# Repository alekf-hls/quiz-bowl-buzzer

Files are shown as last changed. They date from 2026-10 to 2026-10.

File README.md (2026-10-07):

# Quiz Bowl Buzzer

A wireless quiz bowl buzzer set: one ESP32 team station per team (up to 4 teams, 8 wired player buttons each) talking to an ESP32-S3 base that runs its own Wi-Fi network and serves a host page and a scoreboard.

Start with the [design doc](design/buzzer-design-v0.md).

- `design/` design doc, starter kit plan, wiring diagram, page previews
- `enclosures/` 3D-printable boxes (OpenSCAD sources and STLs), see [enclosures/README.md](enclosures/README.md)
- `firmware/base/data/` host page (`host.html`) and scoreboard (`board.html`) served by the base

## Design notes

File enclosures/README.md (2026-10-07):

# Quiz Bowl Buzzer enclosures

Parametric OpenSCAD (tested with OpenSCAD 2021.01) plus ready-to-print STLs for:

| Part | File | Outer size (W x D x H) |
|---|---|---|
| Team station box | `stl/team_station_box.stl` | 151 x 101 x 47 mm |
| Team station lid | `stl/team_station_lid.stl` | 151 x 101 x 3 mm (+4 mm lip) |
| Base station box | `stl/base_station_box.stl` | 180 x 125 x 47 mm |
| Base station lid | `stl/base_station_lid.stl` | 180 x 125 x 3 mm (+4 mm lip) |

Fits a 180 x 180 mm bed or larger. Previews are in `preview/`.

## What's where

**Team station** (one per team)
- Front: 8 holes for 3.5 mm TRRS panel jacks, a player light (5 mm RGB LED) above each one, seat numbers 1-8 below.
- Back: ESP32 USB opening (programming), the UPS board's USB-C opening (charging and wall power) and a 3 mm window for its charge LED.
- Right side: slide power switch.
- Lid: a 30 mm team button labelled TEAM (for playing as a team without the player buttons), big team number and "TEAM n" label. Print the lid in the team's colour. `team_button = false` removes the button hole. (`lid_led = true` adds an extra LED hole on the lid.)
- Inside: 4 tall (23 mm) standoffs for a 70 x 90 mm protoboard carrying the ESP32 DevKitC and ULN2803, with the 18650 holder in rails underneath it; a raised pocket for the USB-C UPS board. The area under the team button is kept clear.

**Base station**
- Lid, front to back: Arm / Correct / Wrong / Reset buttons with labels; a row of 4 team lights (5 mm RGB LEDs) numbered 1-4 (`teams` sets the count); the 1.3" OLED window (chamfered, with 4 M2 standoffs underneath for the module), Armed and Locked LEDs to its left and the buzzer grille with a glue-in ring to its right.
- Back: ESP32-S3 USB opening (wide enough for both USB-C ports).
- Right side: UPS board USB-C with a charge LED window, and the slide power switch.
- Inside: protoboard standoffs, 18650 rails along the back wall, UPS board pocket.

## Changing it

Open `team_station.scad` or `base_station.scad`; everything is a named variable at the top. Common ones:

- `team_label`, `team_num`: lid text per team (e.g. `openscad -D 'team_num="3"' -D 'team_label="TEAM 3"' -D 'part="lid"' -o lid3.stl team_station.scad`).
- `jacks`: number of player jacks (the box doesn't shrink automatically; reduce `X` too if you want a smaller box).
- `batt = false`: USB-only, drops the battery rails, UPS board pocket, switch and its USB-C opening.
- `btn_hole`: host button hole size (24.2 for 24 mm arcade, 16.2 or 12.2 for panel-mount momentaries).
- `screw_mode` in `common.scad`: `"selftap"` (M3 straight into plastic) or `"insert"` (M3 heat-set inserts).

Export: `openscad -D 'part="box"' -o box.stl team_station.scad` and the same with `part="lid"`. `part="assembly"` shows both.

## Assumed part dimensions (measure yours before printing)

| Part | Assumed | Where it matters |
|---|---|---|
| ESP32 DevKitC 38-pin | ~55 x 28 mm, micro-USB on a short end | USB opening centred 22 mm from the left inner wall |
| ESP32-S3 DevKitC-1 | ~63 x 26 mm, two USB-C on a short end | 24 x 8 mm opening at the same height |
| Board stack | standoff (23 mm station, 5 mm base) + 1.6 mm protoboard + 8.5 mm female header + DevKitC | sets the USB height (`esp_usb_z`: 36 mm station, 18 mm base) |
| Team button | 30 mm snap-in arcade button, ~33 mm bezel, ~35 mm below the lid | 30 mm hole (`team_btn_hole`; some need 28 mm) |
| Protoboard | 70 x 90 mm, M2 holes 2 mm in from each corner | standoff positions (M2 self-tap pilot) |
| 3.5 mm TRRS panel jack | 6 mm thread with nut, ~12 mm deep behind the panel | 6.2 mm holes, 14 mm pitch, in a 2.4 mm wall |
| Player / team lights | PL9823 5 mm RGB LED, pushed in from inside (flange stops it) | 5.1 mm holes; station lights 13 mm above the jacks, base lights 28 mm apart |
| OLED | 1.3" SH1106 128x64 I2C module, PCB 35.4 x 33.5 mm, M2 holes 30.5 x 28.5 mm, glass centred ~1.5 mm off the PCB centre | 31 x 17 mm window; check `oled_pcb_dy` and `oled_holes` against your module, they vary between sellers |
| 18650 holder | single cell, ~77 x 21 x 19 mm | retaining rails, fix with double-sided tape |
| USB-C UPS board (charger + boost, pass-through) | ~30 x 25 mm, USB-C on a short edge | pocket, 12 x 7 mm opening (room for the plug), 3 mm LED window beside it; these boards vary a lot, measure yours |
| Slide switch | ~12 x 6 mm body, 8.5 x 4 mm actuator | 8.9 x 4.6 mm slot plus two 2.2 mm screw holes 15 mm apart |
| Host buttons | 24 mm snap-in arcade buttons, ~33 mm deep with microswitch | 45 mm inner height; the design doc listed tactile switches, change `btn_hole` if you stay with those |
| Buzzer | 12 mm round active 5 V buzzer | glue-in ring under the lid |
| Armed / Locked LEDs | 5 mm | 5.2 mm holes, press fit or glue |

## Power

Every unit has an 18650 and a USB-C UPS board: plug any USB-C phone charger into the outside port and it runs from the wall while charging, unplug and it keeps running on the battery. The ESP32's own USB port is also reachable, for firmware updates.

## Printing

- PLA or PETG, 0.2 mm layers, 3 walls, 15-20 % infill, no supports needed.
- Box prints opening up. Lid STLs are already flipped so the top face is on the bed (labels print as clean recesses).
- If holes come out tight, drill them to size; jack and switch holes are the ones that matter.

## Hardware per enclosure

- 4 x M3 x 10 mm screws for the lid (or 4 x M3 heat-set inserts with `screw_mode = "insert"`).
- 4 x M2 x 5 mm self-tapping screws for the protoboard (base: 4 more for the OLED).
- 4 stick-on rubber feet.

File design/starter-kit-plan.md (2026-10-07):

# Quiz Bowl Buzzer: Starter Kit and Add-ons

Date: 2026-10-07. Prices are rough single-unit online prices (AliExpress/Amazon); they'll vary.
Goal: a cheap set you can play with now, and add to without rebuilding anything.

## Rules that keep add-ons cheap
- **Build every station for the max from day one.** Each team station gets all 8 player jacks and 8 player lights fitted even before any player buttons exist (under $0.70 per seat). Adding players later is then just plugging in buttons.
- **Use 4-wire TRRS cables** on every player button, even ones without lights, so lit buttons can plug in later.
- **Firmware detects what's fitted**: no player buttons, no OLED, no ULN2803, any number of stations (1-4) all just work.
- **Battery + wall power is built in from the start.** To save ~$20 you can skip the batteries at first and run every unit from a USB-C wall charger; the board and USB-C socket are the same either way.
- **Any phone or laptop is the scoreboard** until you want a dedicated HDMI box.

## Stage 1: Starter kit, base + 2 team stations, team buttons only (~$80)
Play a full team game right away: each team buzzes with the **team button** built into its station. Includes lockout, scoring, host page, scoreboard in a browser, which-team lights on the base, and USB-C rechargeable batteries that also run from wall power. No individual player buttons yet; the jacks are ready for them.

| Item | Qty | Each | Total |
|---|---|---|---|
| ESP32-S3 DevKitC (base) | 1 | $10 | $10 |
| Base parts: 4 tactile buttons, active buzzer, 2N2222, 2 LEDs, resistors | 1 set | $5 | $5 |
| PL9823 5 mm RGB LED (4 team lights on base) | 4 | $0.25 | $1 |
| ESP32 DevKitC (team stations) | 2 | $5 | $10 |
| 30 mm team button on each station lid | 2 | $1 | $2 |
| TRRS panel jacks (all 8 per station, ready for player buttons) | 16 | $0.40 | $6.40 |
| PL9823 5 mm RGB LED (8 player lights per station) | 16 | $0.25 | $4 |
| Perfboard, headers, wire, 1 kΩ/330 Ω/10 kΩ resistors, capacitors | 1 lot | $10 | $10 |
| 3D-printed enclosures: base + 2 stations (filament) | ~300 g | | $6 |
| 18650 cell + holder | 3 | $3.50 | $10.50 |
| USB-C UPS board (charge + boost, pass-through) | 3 | $3 | $9 |
| Slide switch, 1000 µF capacitor | 3 | $0.50 | $1.50 |
| **Stage 1 total** | | | **~$80** (~$60 without batteries, running from wall chargers) |

Even cheaper: leave the jacks and player lights out of the stations for now (−$10, so ~$70). The holes are already in the printed boxes, but you'd be soldering them in later instead of just plugging buttons in.

## Add-ons (any order)

| Add-on | What it adds | Cost |
|---|---|---|
| **Player buttons** | 30 mm arcade button + 2 m TRRS cable + printed housing, plugs into any station jack | ~$3.50 each: ~$14 for 4 on a team, ~$28 for a full team of 8 |
| **Third team** | 1 station (ESP32, team button, 8 jacks, 8 lights, battery + USB-C board) + enclosure | ~$24 |
| **Fourth team** | same | ~$24 |
| **Base screen** | 1.3" OLED showing team name + seat | ~$5 |
| **HDMI scoreboard box** | Raspberry Pi Zero 2 W + case, mini-HDMI cable, power, microSD | ~$35 |
| **Lit buttons (optional)** | ULN2803 per station + 60 mm LED arcade buttons instead of 30 mm | ~$1 per station + ~$3 more per button |

## Totals
- Starter: **~$80**
- Starter + 4 player buttons on each team (2 teams x 4): **~$108**
- Max size (4 teams x 8 player buttons), base screen, batteries, HDMI box, without lit buttons: **~$80 + $24x2 + 32 x $3.50 + $5 + $35 ≈ $280**
- Lit buttons on top: **~+$100**.

**Recommendation:** skip lit buttons. The player light above each jack already shows who buzzed. If you do want them, buy 60 mm LED buttons from the start rather than replacing 30 mm ones.

## Suggested order
1. Starter kit; play team games with the team buttons.
2. Player buttons for both teams when you want to know who buzzed.
3. Base screen ($5) once the moderator wants the player name on the base.
4. Third and fourth stations as you grow.
5. HDMI box when you want the TV scoreboard without a laptop.

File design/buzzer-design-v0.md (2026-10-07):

# Quiz Bowl Buzzer: Design (v1)

Status: draft v1, 2026-10-07. Decisions so far (Alek):
- ESP32 wireless, on the base station's **own Wi-Fi network** (no venue Wi-Fi).
- **Team stations with wired player buttons** (one wireless box per team), chosen over a wireless buzzer per player.
- **Standard scoring**: 10 correct, 15 power, −5 neg.
- **Max size: 4 teams of up to 8 players** (32 buttons). Build target is 4 team stations.

## 1. Goals

- Fair first-buzz detection with lockout: exact within a team, ~1 ms between teams.
- Start with 2 teams x 4 players; grow to 4 teams x 8 with no redesign.
- Host console to arm/reset, see who buzzed, and award points.
- Optional leaderboard on a laptop/TV, served by the base station.
- Few batteries, no cables across the room.

## 2. Architecture

```
 [Player button] x up to 8 --cable--> [Team station ESP32] x up to 4 --ESP-NOW--> [Base station ESP32-S3] --own Wi-Fi--> [Host view + leaderboard (browser)]
   arcade button + LED                 detects presses, lights LEDs,                 arbitration, lockout,                  arm / score / reset,
   3.5 mm TRRS plug                    timestamps from Arm                           scores, web server                     projector view
```

- **Player button**: a 60 mm arcade button with built-in LED in a small housing, on a 2 m 4-conductor 3.5 mm cable (TRRS, headset-style): tip = button signal, ring 1 = LED +5 V, ring 2 = LED return to driver, sleeve = ground. The LED needs its own supply wire, so 3-conductor TRS isn't enough.
- **Team station**: one classic ESP32 DevKitC per team, in a box on the team's table with 8 TRRS jacks, a ULN2803 driver for the button LEDs, a row of 8 **player lights** (one above each jack, see §3a), a built-in **team button** on the lid (§3b), and **battery + wall power** (§3c). It is the only radio for that team.
- **Base station**: one ESP32-S3 with physical host buttons, piezo, status LEDs, a row of 4 **team lights**, a small **OLED display** (see §3a) and **battery + wall power** (§3c). Single source of truth for who buzzed first and the score.
- **Host UI**: the base serves a web page over its own network. Phone or laptop joins and opens `http://192.168.4.1`.

### Own network (SSID)
- SSID like `QuizBowl-1A2B` (last 4 of the base MAC, so two sets in one building don't clash), WPA2 password set in the host view.
- Fixed channel (default 1, changeable in the host view if the room is noisy). Team stations find the base by scanning for that SSID at power-on, lock to its channel, then talk ESP-NOW on it.
- About 10 phones/TVs can join. Team stations don't count; they don't join the network.

### Why ESP-NOW
Connectionless, ~1 ms latency, no router. With at most 8 team stations, the 20-peer ESP-NOW table isn't a constraint, and each station can be a registered, encrypted peer.

## 3. Lockout logic (fairness)

**Within a team** (on the station): every button is on its own GPIO with a hardware interrupt that records `micros()` at the instant of the press. Order between teammates is exact to microseconds; no radio involved.

**Between teams** (on the base):
1. Host presses **Arm**. Base sends `ARM{round_id}` to all stations; each records its local `micros()` at arm.
2. On the first press on a station, it sends `BUZZ{team, seat, elapsed_us}` where `elapsed_us` is time since Arm by its own clock. It retries until the base ACKs. Later presses on the same team are sent too, for stats only.
3. Base waits a **5 ms arbitration window** after the first BUZZ, then picks the lowest `elapsed_us`. Gaps under ~1 ms count as a tie, broken by arrival order.
4. Base sends `LOCK{team, seat}`. The winning player's button LED lights, the station LEDs show which team has it, and the base sounds the tone.
5. **Rules** (standard quiz bowl):
   - *Wrong answer*: host presses **Neg** or **Wrong**; that team is locked out for the rest of the question.
   - *Continue*: base re-arms for teams not locked out.
   - *Reset*: clears lockouts for the next toss-up.
6. Early buzz (before Arm) is ignored or flagged, configurable.

### Wireless timing reliability
- Crystal drift over a 10 s question is about 0.2 ms; Arm reaches every station within a fraction of a millisecond.
- Lost packets are retried until ACKed, so a press is never dropped silently. A station that misses Arm re-syncs and flags itself on the host view.
- Risk is a crowded 2.4 GHz room: mitigated by channel choice and a pre-game signal check per station. With only one radio per team, there's far less traffic than with a radio per player.

## 3a. Who-buzzed indicators

So the moderator can rule on a team answer without the scoreboard, and still see the player when it matters:

**Base station (which team):**
- **4 team lights** in a row, numbered 1-4, one per team station. When a team wins the buzz, its light shows that team's colour (set on the host page). Locked-out teams show dim red; Armed shows all lights soft white.
- **1.3" OLED display** (128x64) above them showing the team name and seat, e.g. `EAGLES  · seat 3`, plus question number and Armed / Locked state.

**Team station (which player):**
- **8 player lights**, one above each jack, labelled 1-8. The winning player's light turns on in the team colour, so the team and moderator can see who buzzed even if the button itself is out of view. The winning player's button light also turns on, as before.
- Between questions the lights show station status: green = connected, blinking amber = searching for base, red = low battery.

**Parts:** both rows use PL9823 5 mm addressable RGB LEDs (WS2812-type, through-hole). They daisy-chain on one data pin, so there's no extra driver chip or wire per LED, and each can show any colour. The ESP32's 3.3 V data signal is at the edge of what a 5 V chain accepts; if the lights flicker on the breadboard, add a 74AHCT125 level shifter (about $0.50) on the data line.

## 3b. Team button

Each team station has a **built-in team button** (30 mm arcade button) on its lid, for games played as a team without getting out the individual buttons.
- Wired inside the box to GPIO35, so nothing to plug in.
- Works alongside the individual buttons: whichever is pressed first counts. A team-button buzz shows as `EAGLES · team` on the base screen, host page and scoreboard, and all 8 player lights flash in the team colour.
- Team mode on the host page (optional): ignores individual buttons, for when they're plugged in but you want team-only play.

## 3c. Power: battery and wall

Every unit (base and each team station) runs from a **built-in 18650 battery and also from any USB-C wall charger**:
- An **18650 cell + USB-C "UPS" board** (charger + 5 V boost with pass-through). Plug in a USB-C charger and the unit runs from the wall while the battery charges; unplug and it carries on from the battery without restarting.
- Pick a board sold as a UPS / uninterrupted (pass-through) module, rated 5 V 1 A or more. Plain IP5306 power-bank boards can drop the output for a moment when the charger is plugged in, which would reboot the ESP32. A 1000 µF capacitor on the 5 V bus helps either way. Test plug/unplug mid-game on the breadboard.
- Estimated run time on one 3000 mAh cell: station ~12 hours, base ~8 hours (it runs the Wi-Fi network). Not yet measured.
- Battery level for every unit shows on the host page.
- Any 5 V USB-C phone charger works for wall power. The HDMI scoreboard Pi runs from the TV's USB port or its own wall charger.

## 4. Team scaling

- Each station stores its `team_id` in flash, set from the host view during pairing. Seat = jack number (1-8).
- Roster check before a game: each player presses once, and the host view marks that seat as present.
- Adding a player = plug in another button. Adding a team = build another station and pair it.
- Team identity: coloured button caps and a coloured station lid per team.
- **Limit**: 8 players per station (a classic ESP32 has enough free pins for 8 buttons + 8 LEDs); more is possible with an I/O expander. Base supports 4 teams (Alek's max); more would need more team lights.

## 5. Host console

Physical (on base): **Arm**, **Correct**, **Wrong**, **Reset**. Works with no phone at all.

Web host view: `firmware/base/data/host.html`, served at `http://192.168.4.1/` (preview: [host-preview.png](host-preview.png)).
- Who buzzed, with seat.
- Buttons: Arm, Correct (+10), Power (+15), Neg (−5), Wrong (no neg), Continue, Next question, Undo.
- **Team names and colours editable** (up to 24 characters). Changes show on the scoreboard as you type; the base saves them to flash so they survive a power cycle.
- Manual ±5 score adjust per team.
- Later: station pairing, player names per seat, signal/battery status, question timer.
- `host.html?demo` runs with no hardware and drives `board.html?demo` open in the same browser.

## 6. Scoreboard / leaderboard (optional)

- Page: `firmware/base/data/board.html`, served by the base at `http://192.168.4.1/board`. Full-screen, dark, readable across a room: team names, scores sorted high to low, who has the buzz, question number. Scores bump when they change; locked-out teams dim.
- Live updates over WebSocket (`/ws`) from the base. Open `board.html?demo` to preview with fake data and no hardware. Preview: [scoreboard-preview.png](scoreboard-preview.png).
- Scores kept in base RAM, mirrored to flash after each change so a reset doesn't lose the game. CSV export from the host view.

### Getting it on a TV
The ESP32 has no video output, so the page is shown by any device with a browser that joins the base's Wi-Fi:
- **Default: Raspberry Pi Zero 2 W on the TV's HDMI** (~$35 with case, mini-HDMI cable, power). Set up once to join `QuizBowl-XXXX` and open `/board` full-screen at boot (kiosk mode). Plug into TV and power, and the scoreboard appears, no keyboard needed.
- **Laptop on HDMI**: join the network, open `/board`, press F11.
- **Any phone, tablet or smart TV browser**: join the network and open the page. Works without HDMI.

## 7. Parts list (2 teams x 4 players, prototype)

> For a cheaper phased build (starter ~$85, no lit buttons or ULN2803 at first), see [starter-kit-plan.md](starter-kit-plan.md).

| Item | Qty | Approx. each | Notes |
|---|---|---|---|
| **Per team station** | | | |
| ESP32 DevKitC (classic, 38-pin) | 2 | $5 | plenty of GPIO |
| ULN2803 LED driver | 2 | $1 | drives 8 button LEDs |
| 3.5 mm TRRS panel jacks | 16 | $0.40 | 8 per station |
| 18650 cell + holder | 3 | $3.50 | one per station + base |
| USB-C UPS board (charge + 5 V boost, pass-through) | 3 | $3 | battery or wall power, see §3c |
| Slide power switch | 3 | $0.20 | |
| 30 mm arcade button (team button) | 2 | $1 | on each station lid |
| Enclosure | 2 | $5 | project box or 3D printed |
| **Per player button** | | | |
| 60 mm arcade button with LED (5 V version) | 8 | $3 | team-coloured caps |
| 2 m 3.5 mm TRRS cable | 8 | $2 | headset extension cable, cut one end into the housing |
| Small button housing | 8 | $1 | 3D printed or cut box |
| **Base station** | | | |
| ESP32-S3 DevKitC | 1 | $10 | |
| Piezo, 4 tactile buttons, LEDs, wire, resistors | 1 set | $5 | |
| PL9823 5 mm addressable RGB LED | 4 base + 8 per station | $0.25 | team / player lights |
| 1.3" OLED 128x64 I²C module (SH1106) | 1 | $5 | base display |
| *Optional:* Raspberry Pi Zero 2 W + case, mini-HDMI cable, 5 V supply, microSD | 1 | $35 | HDMI scoreboard box |

Rough total: **~$115** for 2 stations, 8 buttons and the base. Each extra player ≈ $6; each extra team station ≈ $20 plus its buttons.

**Full set at max size (4 teams x 8 players):** 4 stations (~$22 each with lights) + 32 buttons (~$6 each) + base (~$21) ≈ **$300**, plus ~$35 for the optional HDMI scoreboard Pi.

## 7a. Wiring

Full diagram: [wiring-diagram.svg](wiring-diagram.svg) (PNG copy: wiring-diagram.png).

**Team station (ESP32 DevKitC)**

| Jack | Button input (internal pull-up, 1 kΩ series) | LED output → ULN2803 |
|---|---|---|
| 1 | GPIO13 | GPIO23 → IN1 |
| 2 | GPIO14 | GPIO25 → IN2 |
| 3 | GPIO16 | GPIO26 → IN3 |
| 4 | GPIO17 | GPIO27 → IN4 |
| 5 | GPIO18 | GPIO32 → IN5 |
| 6 | GPIO19 | GPIO33 → IN6 |
| 7 | GPIO21 | GPIO4 → IN7 |
| 8 | GPIO22 | GPIO15 → IN8 |

- Jack n: T → button input via 1 kΩ; R1 → +5 V; R2 → ULN2803 OUTn; S → ground.
- ULN2803 COM (pin 10) → +5 V, GND (pin 9) → ground.
- Player lights: GPIO2 → 330 Ω → DIN of LED 1; DOUT → DIN chained through LED 8. Each LED: +5 V, ground, 100 nF across its power pins; one 470 µF across the 5 V bus at the chain.
- Battery sense: battery + → 100 kΩ → GPIO34 → 100 kΩ → ground.
- Power: 18650 → USB-C UPS board → on/off switch → 5 V bus (ESP32 5V pin, jack R1s, ULN COM). 1000 µF across the 5 V bus.
- Team button: GPIO35 ← 1 kΩ ← button → ground; 10 kΩ pull-up from GPIO35 to 3V3 (GPIO35 has no internal pull-up).
- The 1 kΩ resistors protect the inputs if a plug's +5 V contact brushes the signal line while it is being inserted. Still best to plug buttons in before powering on.

**Base station (ESP32-S3 DevKitC)**

| Function | Pin | Wiring |
|---|---|---|
| Arm / Correct / Wrong / Reset | GPIO4 / 5 / 6 / 7 | tactile button to ground, internal pull-up |
| Buzzer | GPIO8 | 1 kΩ → 2N2222 base; active 5 V buzzer between +5 V and collector; emitter to ground |
| Armed LED (green) | GPIO9 | 220 Ω → LED → ground |
| Locked LED (red) | GPIO10 | 220 Ω → LED → ground |
| Team lights (4 x PL9823) | GPIO11 | 330 Ω → DIN of LED 1, chained; +5 V, ground, 100 nF per LED, 470 µF at the chain |
| OLED display (SH1106, I²C) | GPIO12 SDA, GPIO13 SCL | VCC 3.3 V, GND |
| Power | 18650 → USB-C UPS board → switch → 5 V pin | runs on battery or any USB-C wall charger, same as stations; 1000 µF across 5 V |

## 8. First build steps

1. **Bench radio test**: two ESP32s on USB, ESP-NOW ping-pong, measure round-trip latency.
2. **One station on a breadboard**: 2 buttons with interrupts, print press order and time-since-arm over serial.
3. **Station + base**: ARM / BUZZ / LOCK / reset messages, winner printed by the base.
4. **Fairness test**: two stations triggered from one shared button (test jig) to check tie handling and the arbitration window.
5. **Web host view** from the base (plain HTML + WebSocket, no framework), scoring and lockout rules, undo.
6. **Leaderboard page.**
7. **Hardware build-out**: TRRS cabling, button housings, station enclosures, batteries; then the second team.

## 9. Software layout (proposed repo)

```
firmware/
  common/protocol.h      # message types, shared constants
  station/               # PlatformIO project, ESP32 team station
  base/                  # PlatformIO project, ESP32-S3 base
    data/                # host + board web pages (LittleFS)
docs/
  design.md              # this file
```

PlatformIO + Arduino framework to keep it approachable.

## 10. Open questions

- Do you want a GitHub repo for the firmware? GitHub isn't connected to this project yet.

## 12. Enclosure dimensions for indicators (check against the parts you buy)

| Part | Where | Size | Mounting |
|---|---|---|---|
| 30 mm arcade button (team button) | each station lid | 30 mm snap-in body, ~33 mm bezel | 30 mm hole (some are 28 mm; check part) |
| 18650 cell in holder | base and each station | holder ~77 x 21 x 19 mm | internal clip or screw bosses |
| USB-C UPS board | base and each station | typically ~30 x 25 mm, USB-C on one edge | USB-C cutout ~10 x 4.5 mm in the wall; status LED window if the board has one |
| Slide power switch | base and each station | ~12 x 6 mm body | ~8.5 x 4 mm slot |
| PL9823 5 mm LED | base (x4), each station (x8) | 5 mm dome, ~8.6 mm long body, 4 leads | 5.1 mm hole; base row at 15 mm pitch; station one directly above each jack |
| 1.3" OLED module (SH1106) | base | PCB ~35.5 x 33.5 mm, ~4 mm thick plus header; visible area ~30 x 15 mm | window ~31 x 16 mm, 4 x M2 holes ~30.5 mm apart |
| 3.5 mm TRRS panel jack | each station (x8) | 6 mm thread | 6.2 mm hole, 12 mm minimum jack pitch |
| Label strip | base and station | numbers 1-8 under each light | embossed or printed |

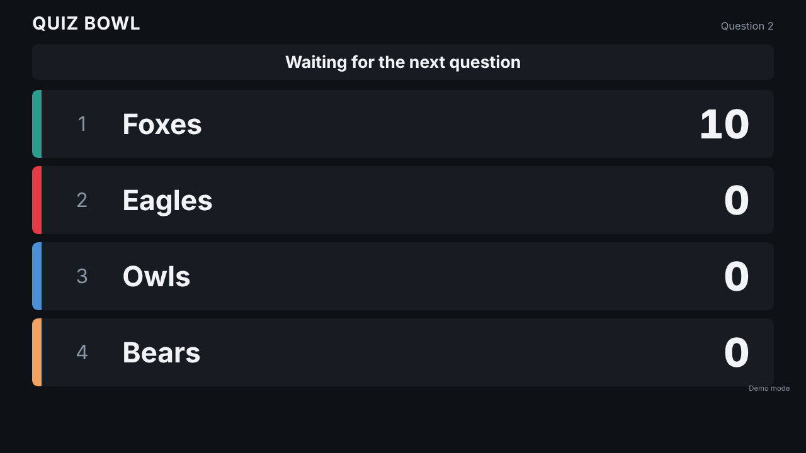
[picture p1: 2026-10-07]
design/scoreboard-preview.png

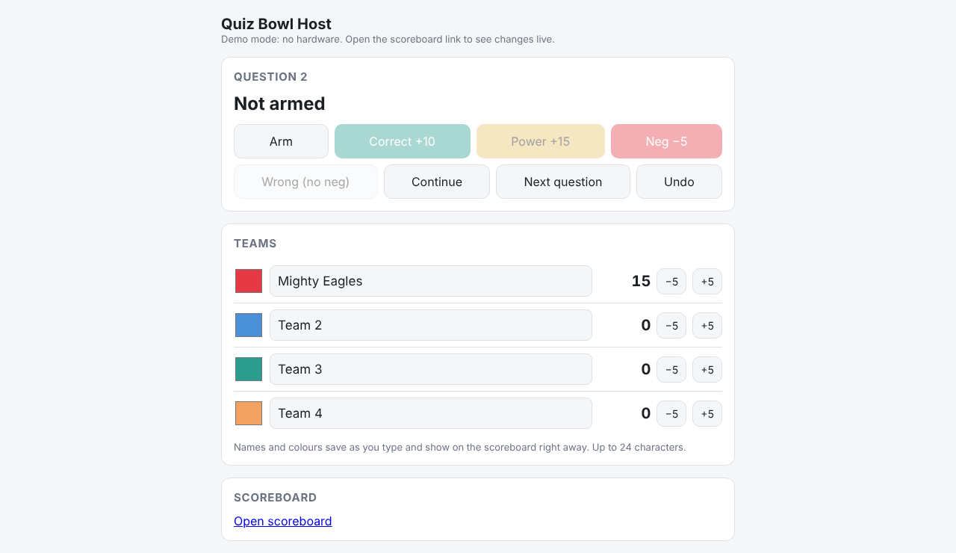
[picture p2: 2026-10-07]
design/host-preview.png

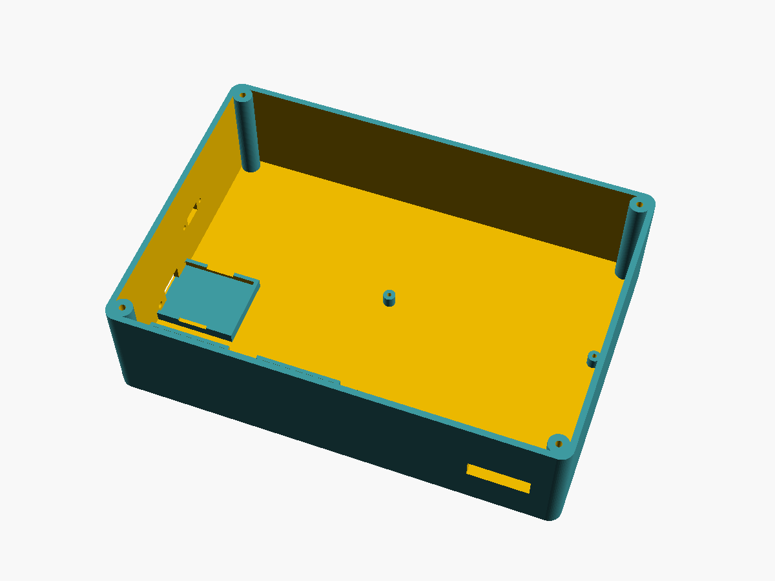
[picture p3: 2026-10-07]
enclosures/preview/base_station_inside.png

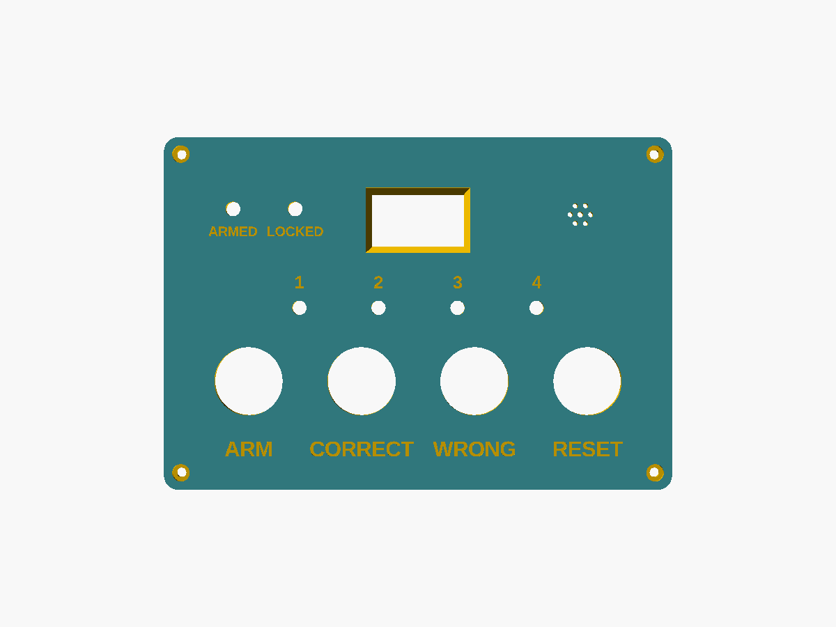
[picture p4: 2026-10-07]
enclosures/preview/base_station_lid_top.png

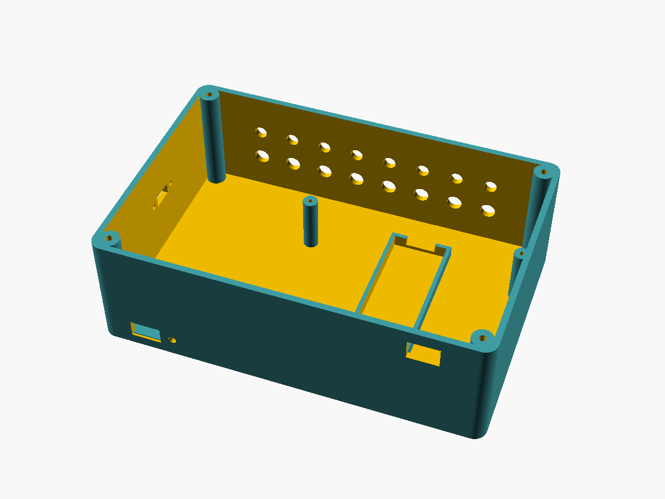
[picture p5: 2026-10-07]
enclosures/preview/team_station_back.png

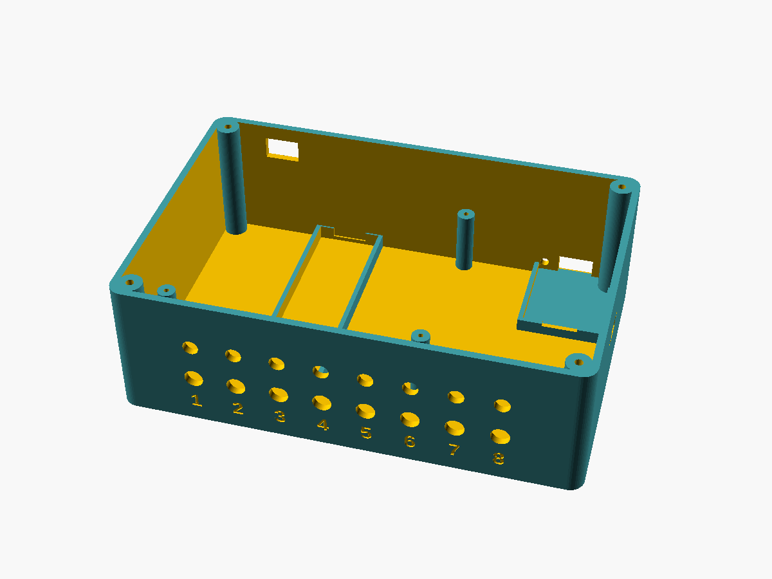
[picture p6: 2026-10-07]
enclosures/preview/team_station_box.png

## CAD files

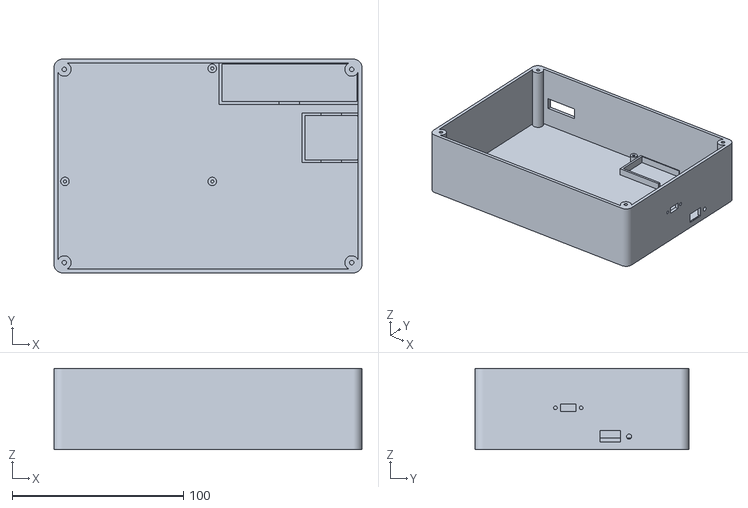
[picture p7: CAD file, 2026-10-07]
enclosures/stl/base_station_box.stl
179.8 x 124.8 x 47.4

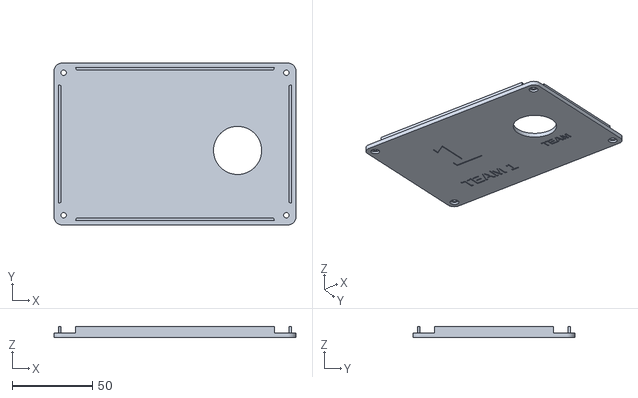
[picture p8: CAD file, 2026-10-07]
enclosures/stl/team_station_lid.stl
150.8 x 100.8 x 7.00

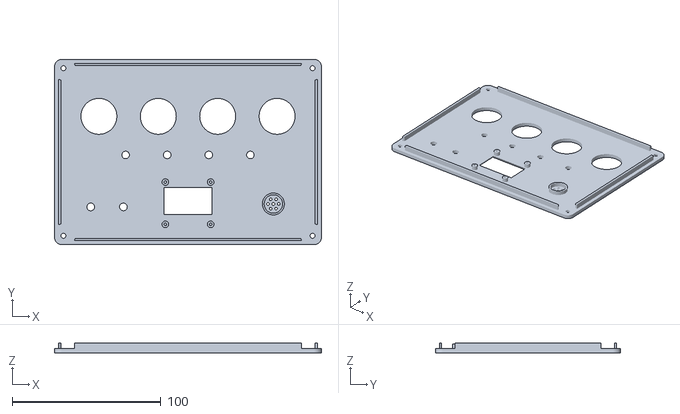
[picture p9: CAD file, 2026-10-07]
enclosures/stl/base_station_lid.stl
179.8 x 124.8 x 7.00

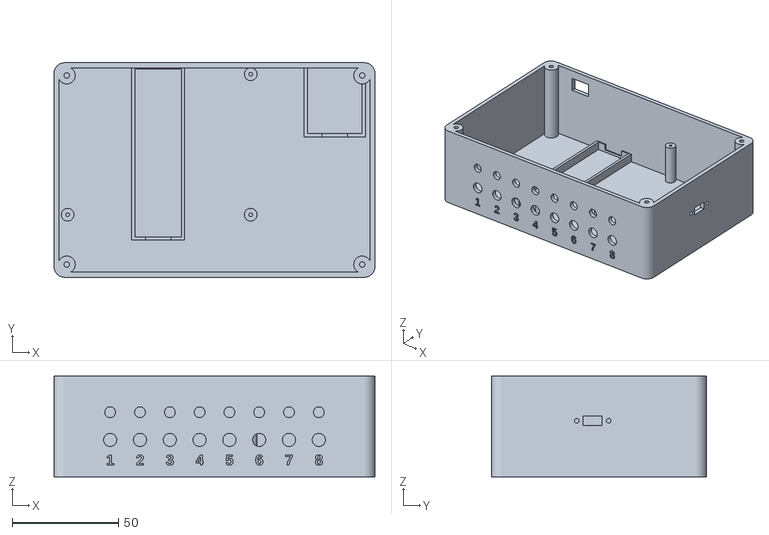
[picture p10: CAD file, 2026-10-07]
enclosures/stl/team_station_box.stl
150.8 x 100.8 x 47.4

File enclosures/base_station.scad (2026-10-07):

// Quiz Bowl Buzzer: base (host) station enclosure (box + lid).
// Four host buttons (Arm / Correct / Wrong / Reset) along the front of the lid,
// a row of team lights (RGB LEDs, one per team) above them, then the OLED window flanked by
// the Armed/Locked LEDs and the buzzer grille. USB on the back wall,
// charger USB-C and power switch on the right wall.
//
// Render one part:  openscad -D 'part="box"' -o box.stl base_station.scad
// part = "box" | "lid" | "assembly"

include <common.scad>

part = "assembly";

// ---- Inside cavity ----
X = 175;
Y = 120;
Z = 45;   // deep enough for 24 mm arcade buttons with microswitches (~33 mm below the lid)

// ---- Host buttons ----
// Default: 24 mm snap-in arcade buttons (hole 24 mm). For 12 mm or 16 mm panel-mount
// momentary buttons set btn_hole to 12.2 or 16.2.
btn_labels = ["ARM", "CORRECT", "WRONG", "RESET"];
btn_hole   = 24.2;
btn_pitch  = 40;
btn_y      = 36;
btn_label_y = 12;

// ---- Team lights (PL9823 5 mm RGB LED, one per team station), numbered 1-n ----
teams       = 4;
light_hole  = 5.1;
light_pitch = 28;
light_y     = 62;
light_label_y = 71;

// ---- OLED (1.3" SH1106 128x64 I2C module, PCB ~35.4 x 33.5 mm) ----
// Window over the glass; the module screws to 4 standoffs under the lid (M2).
oled_center = [X / 2, 93];       // centre of the visible window
oled_win    = [31, 17];          // window (active area is ~29.4 x 14.7)
oled_pcb    = [35.4, 33.5];
oled_holes  = [30.5, 28.5];      // M2 hole spacing on the module
oled_pcb_dy = 1.5;               // PCB centre offset from window centre (+y = toward back)
oled_glass_t = 3.2;              // standoff height: glass + tape, so the glass sits just under the lid

// ---- Status LEDs (5 mm): Armed (green), Locked (red) ----
led_hole   = 5.2;
led_labels = ["ARMED", "LOCKED"];
led_y      = 97;
led_x0     = 22;
led_pitch  = 22;

// ---- Buzzer (12 mm round active buzzer), glued into a ring under a grille ----
piezo_d   = 12.4;
piezo_pos = [X - 30, 95];

// ---- Carrier protoboard with the ESP32-S3 DevKitC, USB-C facing the back wall ----
pcb_w = 90; pcb_d = 70;
pcb_x = 2;  pcb_y = Y - 1 - pcb_d;
standoff_h = 5;
esp_usb_x = pcb_x + 20;
esp_usb_z = 18;
esp_usb_w = 24; esp_usb_h = 8;   // the S3 DevKitC has two USB-C ports side by side

// ---- 18650 + USB-C UPS board: runs from battery or a USB-C wall charger (batt = false: USB only) ----
batt = true;
batt_w = 78; batt_d = 21;               // holder lies along the back wall
batt_x = X - 1 - batt_w; batt_y = Y - 1 - batt_d;
chg_w = 30; chg_d = 25;                 // UPS board (~30 x 25 mm) along x, USB-C facing the right wall
chg_x = X - 0.5 - chg_w; chg_y = 64;
chg_pad = 2;
chg_usb_z = chg_pad + 3.2;
sw_y = 52; sw_z = 22;

function btn_x(i) = X / 2 + (i - (len(btn_labels) - 1) / 2) * btn_pitch;
function led_x(i) = led_x0 + i * led_pitch;
function light_x(i) = X / 2 + (i - (teams - 1) / 2) * light_pitch;
function oled_hole_pts() = [for (sx = [-1, 1], sy = [-1, 1])
    [oled_center[0] + sx * oled_holes[0] / 2, oled_center[1] + oled_pcb_dy + sy * oled_holes[1] / 2]];

module base_box() {
    shell(X, Y, Z) {
        cut_back(Y, esp_usb_x, esp_usb_z, esp_usb_w, esp_usb_h);
        if (batt) {
            cut_right(X, chg_y + chg_d / 2, chg_usb_z, 12, 7);
            translate([X - 1, chg_y + chg_d / 2 + 11, chg_usb_z]) rotate([0, 90, 0]) cylinder(d = 3, h = wall + 2);  // charge LED window
            slide_right(X, sw_y, sw_z);
        }
    }
    pcb_standoffs(pcb_x, pcb_y, pcb_w, pcb_d, h = standoff_h);
    if (batt) {
        retainer(batt_x, batt_y, batt_w, batt_d, h = 5);
        charger_pad(chg_x, chg_y, chg_w, chg_d, pad = chg_pad, open_side = "+x");
    }
}

module base_lid() {
    difference() {
        union() {
            lid(X, Y, Z) {
                for (i = [0 : len(btn_labels) - 1]) {
                    translate([btn_x(i), btn_y, Z - 1]) cylinder(d = btn_hole, h = lid_t + 2);
                    lid_text(Z, btn_x(i), btn_label_y, btn_labels[i], 5.5);
                }
                for (i = [0 : len(led_labels) - 1]) {
                    translate([led_x(i), led_y, Z - 1]) cylinder(d = led_hole, h = lid_t + 2);
                    lid_text(Z, led_x(i), led_y - 8, led_labels[i], 3.5);
                }
                for (i = [0 : teams - 1]) {
                    translate([light_x(i), light_y, Z - 1]) cylinder(d = light_hole, h = lid_t + 2);
                    lid_text(Z, light_x(i), light_label_y, str(i + 1), 4.5);
                }
                // OLED window, chamfered on top so it reads at an angle
                translate([oled_center[0], oled_center[1], Z - 1]) hull() {
                    translate([0, 0, 0.5]) cube([oled_win[0], oled_win[1], 1], center = true);
                    translate([0, 0, 1 + lid_t]) cube([oled_win[0] + 2 * lid_t, oled_win[1] + 2 * lid_t, 0.02], center = true);
                }
                // piezo grille: centre hole + ring of 6
                translate([piezo_pos[0], piezo_pos[1], Z - 1]) {
                    cylinder(d = 2, h = lid_t + 2);
                    for (a = [0 : 60 : 300]) rotate(a) translate([3.6, 0, 0]) cylinder(d = 1.8, h = lid_t + 2);
                }
            }
            // OLED standoffs (M2 self-tap) under the lid
            for (p = oled_hole_pts()) translate([p[0], p[1], Z - oled_glass_t]) difference() {
                cylinder(d = 4.5, h = oled_glass_t + 0.01);
                translate([0, 0, -1]) cylinder(d = 1.8, h = oled_glass_t);
            }
            // ring under the lid that the piezo glues into
            translate([piezo_pos[0], piezo_pos[1], Z - 3]) difference() {
                cylinder(d = piezo_d + 2.4, h = 3.01);
                translate([0, 0, -1]) cylinder(d = piezo_d, h = 5);
            }
        }
    }
}

if (part == "box") base_box();
else if (part == "lid") lid_for_print(X, Y, Z) base_lid();
else {
    color("lightgray") base_box();
    color("steelblue") translate([0, 0, 30]) base_lid();
}

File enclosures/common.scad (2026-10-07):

// Quiz Bowl Buzzer: shared enclosure helpers.
// Coordinates: the inside cavity spans [0,X] x [0,Y], the floor's top face is z=0,
// and the lid's underside sits at z=Z. y=0 is the front wall.

$fn = 48;

// ---- Shell ----
wall       = 2.4;   // side wall thickness
floor_t    = 2.4;   // floor thickness
lid_t      = 3.0;   // lid plate thickness
corner_r   = 5;     // outer corner radius
lip_h      = 4;     // lid locating lip depth
lip_w      = 1.6;   // lid lip thickness
lip_clear  = 0.3;   // gap between lip and wall (per side)

// ---- Lid screws (4 corners) ----
boss_d       = 8;   // corner boss diameter
boss_off     = 3.6; // boss centre from inner walls
screw_mode   = "selftap"; // "selftap" (M3 into plastic) or "insert" (M3 heat-set insert)
pilot_d      = (screw_mode == "insert") ? 4.0 : 2.6;
pilot_depth  = 10;
screw_clear  = 3.4; // M3 clearance hole in lid
screw_head_d = 6.2; // M3 head counterbore
screw_head_h = 1.6;

// ---- Text ----
font      = "Liberation Sans:style=Bold";
deboss    = 0.6;

module rrect(x, y, h, r) {
    // rounded rectangle from [0,0] to [x,y], height h
    hull() for (px = [r, x - r], py = [r, y - r])
        translate([px, py, 0]) cylinder(r = r, h = h);
}

function boss_pts(X, Y) = [[boss_off, boss_off], [X - boss_off, boss_off],
                           [boss_off, Y - boss_off], [X - boss_off, Y - boss_off]];

// Open-top box shell with corner bosses. Children are subtracted (cut-outs).
module shell(X, Y, Z) {
    difference() {
        union() {
            difference() {
                translate([-wall, -wall, -floor_t])
                    rrect(X + 2 * wall, Y + 2 * wall, Z + floor_t, corner_r);
                rrect(X, Y, Z + 1, max(corner_r - wall, 0.5));
            }
            for (p = boss_pts(X, Y)) translate([p[0], p[1], 0]) {
                cylinder(d = boss_d, h = Z);
                // fill boss to the walls so it prints without overhang gaps
                translate([p[0] < X / 2 ? -boss_off : 0, p[1] < Y / 2 ? -boss_off : 0, 0])
                    cube([boss_off, boss_off, Z]);
            }
        }
        for (p = boss_pts(X, Y)) translate([p[0], p[1], Z - pilot_depth]) cylinder(d = pilot_d, h = pilot_depth + 1);
        children();
    }
}

// Lid in assembled orientation (plate from Z to Z+lid_t, lip hanging below).
// Children are subtracted (holes, text).
module lid(X, Y, Z) {
    difference() {
        union() {
            translate([-wall, -wall, Z]) rrect(X + 2 * wall, Y + 2 * wall, lid_t, corner_r);
            translate([0, 0, Z - lip_h]) difference() {
                translate([lip_clear, lip_clear, 0]) rrect(X - 2 * lip_clear, Y - 2 * lip_clear, lip_h, max(corner_r - wall - lip_clear, 0.5));
                translate([lip_clear + lip_w, lip_clear + lip_w, -1]) cube([X - 2 * (lip_clear + lip_w), Y - 2 * (lip_clear + lip_w), lip_h + 2]);
                for (p = boss_pts(X, Y)) translate([p[0], p[1], -1]) cylinder(d = boss_d + 2 * boss_off + 1, h = lip_h + 2);
            }
        }
        for (p = boss_pts(X, Y)) translate([p[0], p[1], Z - 1]) {
            cylinder(d = screw_clear, h = lid_t + 2);
            translate([0, 0, 1 + lid_t - screw_head_h]) cylinder(d = screw_head_d, h = screw_head_h + 1);
        }
        children();
    }
}

// ---- Interior fittings ----

// Standoffs for a rectangular PCB/protoboard: board footprint w x d at (x0,y0),
// holes inset `inset` from each corner, M2 self-tap pilot.
module pcb_standoffs(x0, y0, w, d, inset = 2, h = 5, od = 5, pilot = 1.8) {
    for (px = [x0 + inset, x0 + w - inset], py = [y0 + inset, y0 + d - inset])
        translate([px, py, 0]) difference() {
            cylinder(d = od, h = h);
            translate([0, 0, 0.6]) cylinder(d = pilot, h = h);
        }
}

// Low rails around a rectangular part so it can be taped/glued in place.
module retainer(x0, y0, w, d, h = 4, t = 1.6, clear = 0.4, open_side = "") {
    difference() {
        translate([x0 - clear - t, y0 - clear - t, 0]) cube([w + 2 * (clear + t), d + 2 * (clear + t), h]);
        translate([x0 - clear, y0 - clear, -1]) cube([w + 2 * clear, d + 2 * clear, h + 2]);
        // open one side (e.g. the side a connector faces)
        if (open_side == "+y") translate([x0, y0 + d - 1, -1]) cube([w, 10, h + 2]);
        if (open_side == "+x") translate([x0 + w - 1, y0, -1]) cube([10, d, h + 2]);
        // finger notches on the long sides for removal
        translate([x0 + w / 2 - 6, y0 - 10, 1.5]) cube([12, d + 20, h]);
    }
}

// Raised pad with rails for a USB-C charger / UPS board.
module charger_pad(x0, y0, w, d, pad = 2, open_side = "+y") {
    translate([x0 - 2, y0 - 2, 0]) cube([w + 4, d + 4, pad]);
    translate([0, 0, pad]) retainer(x0, y0, w, d, h = 2.5, open_side = open_side);
}

// Rectangular hole through the back wall (y = Y), centred at (x, z).
module cut_back(Y, x, z, w, h, r = 1) {
    translate([x - w / 2, Y - 1, z - h / 2]) cube([w, wall + 2, h]);
}
// Rectangular hole through the right wall (x = X), centred at (y, z).
module cut_right(X, y, z, w, h) {
    translate([X - 1, y - w / 2, z - h / 2]) cube([wall + 2, w, h]);
}

// Snap-in rocker switch cut-out in the right wall, with the wall thinned around it
// from inside so the snap tabs can grip.
module rocker_right(X, y, z, w = 19.2, h = 13.0, panel = 1.6) {
    cut_right(X, y, z, w, h);
    translate([X - 0.01, y - w / 2 - 3, z - h / 2 - 3])
        cube([wall - panel + 0.01, w + 6, h + 6]);
}

// Slide power switch in the right wall: slot for the actuator plus two M2 screw
// holes either side (typical 12 x 6 mm body, screw holes 15 mm apart).
module slide_right(X, y, z, slot = [8.5, 4.2], screw_pitch = 15, screw_d = 2.2) {
    cut_right(X, y, z, slot[0] + 0.4, slot[1] + 0.4);
    for (s = [-1, 1]) translate([X - 1, y + s * screw_pitch / 2, z]) rotate([0, 90, 0]) cylinder(d = screw_d, h = wall + 2);
}

// Small round window in the back wall (y = Y), e.g. for a charge LED.
module hole_back(Y, x, z, d = 3) {
    translate([x, Y - 1, z]) rotate([-90, 0, 0]) cylinder(d = d, h = wall + 2);
}

// Debossed text on the front outer wall face (y = -wall), centred at (x, z).
module front_text(x, z, s, size = 5) {
    translate([x, -wall + deboss, z]) rotate([90, 0, 0])
        linear_extrude(deboss + 1) text(s, size = size, font = font, halign = "center", valign = "center");
}

// Debossed text on the lid top (z = Z + lid_t), centred at (x, y).
module lid_text(Z, x, y, s, size = 5) {
    translate([x, y, Z + lid_t - deboss]) linear_extrude(deboss + 1)
        text(s, size = size, font = font, halign = "center", valign = "center");
}

// Lid ready to print: flipped so the top face lies on the bed.
module lid_for_print(X, Y, Z) {
    translate([0, Y, Z + lid_t]) rotate([180, 0, 0]) children();
}

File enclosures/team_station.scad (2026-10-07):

// Quiz Bowl Buzzer: team station enclosure (box + lid).
// One per team. 8 player jacks on the front with a player light (RGB LED) above
// each, USB + charger on the back, power switch on the right, and a big team
// button plus team label on the lid.
// Print the lid in the team's colour.
//
// Render one part:  openscad -D 'part="box"' -o box.stl team_station.scad
// part = "box" | "lid" | "assembly"

include <common.scad>

part       = "assembly";
team_label = "TEAM 1";     // debossed on the lid
team_num   = "1";          // large number on the lid ("" for none)

// ---- Inside cavity ----
X = 146;  // width (along the jacks)
Y = 96;   // depth
Z = 45;   // height, floor to lid underside

// ---- Player jacks (3.5 mm TRRS panel jack with M6 nut) ----
jacks       = 8;
jack_pitch  = 14;
jack_hole   = 6.2;
jack_z      = 15;
jack_labels = true;   // debossed seat numbers below each jack

// ---- Player lights (PL9823 5 mm RGB LED, pushed in from inside, one above each jack) ----
light_hole = 5.1;
light_z    = 28;      // keep below the lid lip (Z - lip_h)

// ---- Team button (30 mm snap-in arcade button, ~33 mm bezel, ~35 mm below the lid) ----
team_button   = true;
team_btn_hole = 30;               // some are 28 mm
team_btn_pos  = [112, 52];        // the area under it is kept clear

// ---- Carrier protoboard (ESP32 DevKitC + ULN2803 soldered/socketed on it) ----
// Sits on tall standoffs with the 18650 holder underneath it.
pcb_w = 90; pcb_d = 70;           // standard 70 x 90 mm protoboard
pcb_x = 2;  pcb_y = Y - 1 - pcb_d;
standoff_h = 23;

// ESP32 DevKitC (38-pin, ~55 x 28 mm) on female headers, micro-USB facing the back wall
esp_usb_x = pcb_x + 20;           // USB centre along the back wall
esp_usb_z = 36;                   // floor + standoff + board + header + DevKitC
esp_usb_w = 12; esp_usb_h = 8;    // room for a micro-USB plug overmold

// ---- 18650 holder (single cell, ~77 x 21 x 19 mm), under the protoboard, long axis front-to-back ----
batt      = true;
batt_w = 21; batt_d = 78;
batt_x = 36; batt_y = Y - 1 - batt_d;

// ---- USB-C UPS board (charger + 5 V boost with pass-through, ~30 x 25 mm), USB-C facing the back wall ----
// Runs the station from a USB-C wall charger and charges the 18650 at the same time.
chg_w = 25; chg_d = 30;
chg_x = 117; chg_y = Y - 0.5 - chg_d;
chg_led = true;                   // 3 mm window beside the USB-C for the board's charge LED
chg_pad = 2;
chg_usb_z = chg_pad + 3.2;
chg_usb_w = 12; chg_usb_h = 7;

// ---- Slide power switch (~12 x 6 mm body, 8.5 x 4 mm slot) on the right wall ----
sw_y = 45; sw_z = 24;

// ---- Lid ----
lid_led  = false;        // extra 5 mm LED on the lid (the player lights already show status)
led_hole = 5.2;
led_pos  = [X - 18, 16];

function jack_x(i) = X / 2 + (i - (jacks - 1) / 2) * jack_pitch;

module station_box() {
    shell(X, Y, Z) {
        for (i = [0 : jacks - 1]) {
            translate([jack_x(i), 1, jack_z]) rotate([90, 0, 0]) cylinder(d = jack_hole, h = wall + 2);
            translate([jack_x(i), 1, light_z]) rotate([90, 0, 0]) cylinder(d = light_hole, h = wall + 2);
            if (jack_labels) front_text(jack_x(i), jack_z - 9.5, str(i + 1), 5);
        }
        cut_back(Y, esp_usb_x, esp_usb_z, esp_usb_w, esp_usb_h);
        if (batt) {
            cut_back(Y, chg_x + chg_w / 2, chg_usb_z, chg_usb_w, chg_usb_h);
            if (chg_led) hole_back(Y, chg_x + chg_w / 2 - 11, chg_usb_z, 3);
            slide_right(X, sw_y, sw_z);
        }
    }
    pcb_standoffs(pcb_x, pcb_y, pcb_w, pcb_d, h = standoff_h, od = 6);
    if (batt) {
        retainer(batt_x, batt_y, batt_w, batt_d, h = 5);
        charger_pad(chg_x, chg_y, chg_w, chg_d, pad = chg_pad, open_side = "+y");
    }
}

module station_lid() {
    lid(X, Y, Z) {
        if (lid_led) translate([led_pos[0], led_pos[1], Z - lip_h - 1]) cylinder(d = led_hole, h = lid_t + lip_h + 2);
        if (team_button) translate([team_btn_pos[0], team_btn_pos[1], Z - 1]) cylinder(d = team_btn_hole, h = lid_t + 2);
        if (team_button) lid_text(Z, team_btn_pos[0], team_btn_pos[1] - 24, "TEAM", 6);
        text_x = team_button ? 46 : X / 2;   // shift the text left to make room for the button
        if (team_num != "") lid_text(Z, text_x, Y / 2 + 10, team_num, 34);
        lid_text(Z, text_x, 18, team_label, 9);
    }
}

if (part == "box") station_box();
else if (part == "lid") lid_for_print(X, Y, Z) station_lid();
else {
    color("lightgray") station_box();
    color("tomato") translate([0, 0, 30]) station_lid();
}

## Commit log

2026-10-07 Initial import of design, enclosures and firmware pages
    Claude-Session: https://claude.ai/code/session_01PbGr9VZd3NxZwqdehiXhkx
    [base_station.scad, base_station_box.stl, base_station_lid.stl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]
2026-10-07 Sync design, enclosures and firmware from project files
    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
    [base_station.scad, base_station_box.stl, base_station_lid.stl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]
2026-10-10 Switch player buttons to Cat6 (RJ45) and drop button lights
    Player buttons are 30 mm unlit arcade buttons on Cat6 patch cables (pins 1/2 only).
    Station uses 8 RJ45 keystone jacks; ULN2803 removed; team button moves to GPIO23.
    Player lights on the station show who buzzed. Starter ~$85, full set ~$275.
    Claude-Session: https://claude.ai/code/session_01Fgxt88sBYxrMotSFxhxikB
2026-10-10 Enclosures: Cat6 (RJ45 keystone) player jacks on the team station
    Eight snap-in keystone cut-outs replace the 3.5 mm TRRS holes (TRRS kept as
    jack_type option). Box grows to 175 x 118 x 47 mm to fit the deeper jacks;
    player lights and seat numbers stay above each jack.
    Claude-Session: https://claude.ai/code/session_013rXfiCeHQaf5SztFyVr8o3
2026-10-10 Enclosures: match keystone size and pitch from the design doc
    Keystone cut-outs 14.9 x 19.2 mm at 20 mm pitch (design doc §12); team
    station widens to 179 x 118 x 47 mm. Drop the ULN2803 mention.
    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
